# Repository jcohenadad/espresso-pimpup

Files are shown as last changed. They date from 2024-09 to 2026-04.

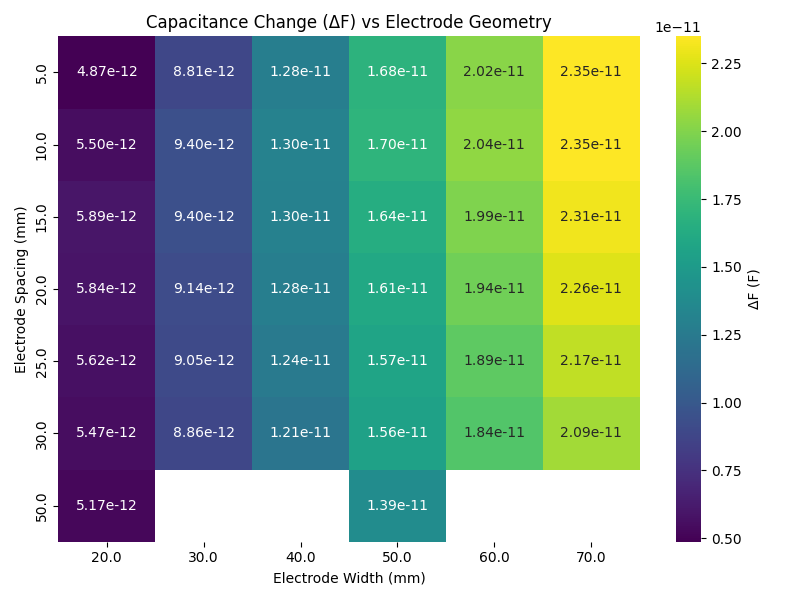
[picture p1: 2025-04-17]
CST/result_sweep.png

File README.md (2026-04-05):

# Espresso pimp up ☕

DIY project to pimp up my espresso machine to display various measures

## Material

- Power
  - [MEAN WELL USA Inc. RS-15-5 AC/DC CONVERTER 5V 15W](https://www.digikey.ca/en/products/detail/mean-well-usa-inc/RS-15-5/7706168)
- Display
  - [Graphic LCD Display Module IPS (In-Plane Switching) SPI 1.69"](https://www.digikey.com/en/products/detail/seeed-technology-co-ltd/104990802/21526011)
  - [CONN HEADER SMD 8POS 1.25MM](https://www.digikey.ca/en/products/detail/hirose-electric-co-ltd/DF13C-8P-1-25V-21/3977750)
  - [8 Position (pitch 1.25mm) Cable Assembly Rectangular Socket to Socket 450.00mm](https://www.digikey.ca/en/products/detail/molex/0151340805/6198210)
  - 4x 2mm metric threading screws https://github.com/jcohenadad/espresso-pimpup/issues/42
- Temperature
  - [K Type Thermocouple Temperature Sensor](https://www.amazon.ca/MECCANIXITY-Thermocouple-Temperature-Sensor-Stainless/dp/B0C998V2DP)
  - [Thermocouple Amplifier MAX31855](https://www.amazon.ca/dp/B00SK8NDAI)

### Water level
| Item | Quantity | Description |
| ---- | --- | --- |
| [FDC1004DGSR](https://www.digikey.ca/en/products/detail/texas-instruments/FDC1004DGSR/5250523) | 1 | 4-channel 16-bit capacitance-to-digital converter |
| [LCQT-MSOP10](https://www.digikey.ca/en/products/detail/aries-electronics/LCQT-MSOP10/4754589) | 1 | To create the breakout board for the FDC1004 chip |
| [WR-PHD 2.54 MM SOCKET HEADER 5 P](https://www.digikey.ca/en/products/detail/w%C3%BCrth-elektronik/61300511821/16608594) | 2 | To plug the breakout board on the main PCB |
| [C0603C104M4RACTU](https://www.digikey.ca/en/products/detail/kemet/C0603C104M4RACTU/411098) | 1 | Decoupling Capacitor |
| [RC0603FR-074K7L](https://www.digikey.ca/en/products/detail/yageo/rc0603fr-074k7l/727212) | 2 | Pull-up Resistors for I2C |

## Pictures

https://photos.app.goo.gl/eQaupZRUNoXkHYi69

## Upload/Monitor Arduino code

Using CLI (you need to adjust the correct port):

```shell
# Compile
arduino-cli compile --fqbn arduino:avr:nano ArduinoEspressoSensor/
# Upload
arduino-cli upload ArduinoEspressoSensor -b arduino:avr:nano -p /dev/cu.usbserial-BG0046HD
# Monitor
arduino-cli monitor -p /dev/cu.usbserial-BG0046HD --config 9600
```

## Calibration

Before using the setup, some calibration is needed.

### Water tank

- Activate debug mode: `DEBUG_CAPACITANCE false`
- Check capacitance values for empty and full tank.
- Enter respective values for variables `LOWER_BOUND` and `UPPER_BOUND`

### Timer

Timer for brewing duration is based on the variable `pressureThreshold`, which can be adjusted if needed.

## References

This project is inspired by the following sources:
- https://www.youtube.com/watch?v=4V0a9dfkx9Q
- https://github.com/PostModernDesign/RancilioBrain/blob/master/RancilioBrain.md
- https://github.com/urbantrout/bleeding-edge-ranciliopid/tree/master?tab=readme-ov-file
- https://clevercoffee.de/rancilio-silvia-demontage/
- https://clevercoffee.de/gaggia-classic-9480/
- https://clevercoffee.de/rancilio-silvia-e-konstantin/
- https://clevercoffee.de/rancilio-silvia-e-sebi/
- https://www.youtube.com/watch?v=AzQRCUg6E9g
- https://optimalprimate.github.io/projects/2020/11/14/coffee.html
- https://github.com/mwood77/koffie
  - https://www.seattlecoffeegear.com/cdn/shop/files/silvia-pid-installation-guide.pdf?v=8847236618586878957
- https://www.reddit.com/r/ranciliosilvia/search/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
- https://github.com/brycesub/silvia-pi?tab=readme-ov-file

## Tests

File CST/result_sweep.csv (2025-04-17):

3D Run ID | electrode_spacing | electrode_width | water_height | Mesh Pass | 1D Results\Es Solver\Capacitance Matrix\C potential, ground
1 | 10 | 20 | 20 | 6 | -2.1493e-12
2 | 10 | 50 | 20 | 6 | -3.38278e-12
3 | 50 | 20 | 20 | 6 | -6.30386e-13
4 | 50 | 50 | 20 | 6 | -1.57864e-12
5 | 10 | 20 | 180 | 6 | -7.64647e-12
6 | 10 | 50 | 180 | 5 | -2.03387e-11
7 | 50 | 20 | 180 | 6 | -5.80162e-12
8 | 50 | 50 | 180 | 6 | -1.5434e-11
9 | 5 | 20 | 20 | 6 | -3.60719e-12
10 | 5 | 30 | 20 | 6 | -4.11443e-12
11 | 5 | 40 | 20 | 6 | -4.1285e-12
12 | 5 | 50 | 20 | 6 | -4.49879e-12
13 | 5 | 60 | 20 | 6 | -5.18666e-12
14 | 5 | 70 | 20 | 6 | -5.56035e-12
15 | 10 | 30 | 20 | 6 | -2.61785e-12
16 | 10 | 40 | 20 | 6 | -2.92457e-12
17 | 10 | 60 | 20 | 6 | -3.7167e-12
18 | 10 | 70 | 20 | 6 | -4.18799e-12
19 | 15 | 20 | 20 | 6 | -1.49111e-12
20 | 15 | 30 | 20 | 6 | -1.97542e-12
21 | 15 | 40 | 20 | 6 | -2.36479e-12
22 | 15 | 50 | 20 | 6 | -2.82149e-12
23 | 15 | 60 | 20 | 5 | -3.23191e-12
24 | 15 | 70 | 20 | 6 | -3.53614e-12
25 | 20 | 20 | 20 | 6 | -1.18861e-12
26 | 20 | 30 | 20 | 6 | -1.60755e-12
27 | 20 | 40 | 20 | 6 | -2.05532e-12
28 | 20 | 50 | 20 | 6 | -2.48066e-12
29 | 20 | 60 | 20 | 6 | -2.84073e-12
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

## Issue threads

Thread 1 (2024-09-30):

Ultrasonic sensor does not work

jcohenadad, 2024-09-30:
I have the PWM DC5V Ultrasonic ranging sensor ultrasonic waterproof distance sensor waterproof probe RS485. It produces constant output between PWM and GND. It suggests it is likely relying on RS485 communication, which requires a RS485 to TTL converter module.

I might get another probe, such as the [DYP-A02YY Waterproof sensor](https://forum.arduino.cc/t/dyp-a02yy-waterproof-sensor/1154338). Links
- https://www.amazon.ca/-/fr/Taidacent-D%C3%A9tecteur-d%C3%A9tection-stationnement-ultrasonique/dp/B082D96911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
- UART: https://www.amazon.ca/dp/B0CLVSQ7H5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
- https://www.aliexpress.com/item/1005003107797097.html

Related resource:
- https://forum.arduino.cc/t/help-understanding-breaking-down-this-code/699362/12
- https://forum.arduino.cc/t/monitoring-the-level-of-an-underground-water-tank/1147820/29

Datasheet of sensor: https://www.dypcn.com/uploads/A02-Datasheet.pdf
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

jcohenadad, 2024-10-15:
Additional debugging, useful ressource:
- https://forum.arduino.cc/t/dyp-a02yy-waterproof-sensor/1154338/18
- https://forum.arduino.cc/t/sensor-shows-the-same-value-a02yyuw/859239/7

jcohenadad, 2024-10-17:
Ended up buying an [HC-SR04](https://www.amazon.ca/dp/B07RGB4W8V?ref=ppx_yo2ov_dt_b_fed_asin_title).

Closed 2024-12-06.

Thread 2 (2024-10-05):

Timer for brew switch button

jcohenadad, 2024-10-05:
To implement a timer for measuring the duration of an espresso shot on the Rancilio Silvia machine, you'll need to wire the Arduino to detect when the brew button is switched on and off. Here's a guide on how to connect the Arduino to the machine and the code to control the timer:

1. Wiring the Arduino to the Rancilio Silvia Machine:
The Rancilio Silvia’s brew switch controls the power to the pump or a solenoid valve. We can use the state of this switch to detect when the brew starts and stops. One way to do this is by using an opto-isolator (optocoupler) or a relay module to safely interface the 120V AC or 230V AC voltage with the Arduino, which operates at a lower voltage.

Note: If you're not comfortable working with high voltage, consider using a safe sensor like a current sensor or work with an electronics professional.

Components Needed:
Optocoupler (Opto-isolator): For isolating the high voltage AC and low voltage DC.
Relay Module: As an alternative to the optocoupler, a relay module can be used to interface high voltage safely.
Resistors (for current limiting if needed).
Wires.
Arduino Board.
Basic Wiring Steps:
Identify the Brew Switch on the Rancilio Silvia:

Open the case of the Rancilio Silvia to access the brew switch.
Find the two terminals of the brew switch where it connects to the pump or solenoid valve.
Connect the Optocoupler or Relay to the Brew Switch:

Connect the input side of the optocoupler or relay module to the brew switch terminals.
When the switch is turned on, it should close the circuit on the input side, allowing the optocoupler or relay to activate.
Connect the Optocoupler or Relay to the Arduino:

The output side of the optocoupler or relay should connect to a digital input pin on the Arduino (e.g., Digital Pin 2).
Connect the GND of the Arduino to the GND of the optocoupler/relay module.
Optionally, connect a pull-down resistor (e.g., 10kΩ) between the digital input pin and GND to ensure the pin reads LOW when the brew switch is off.

Here's a simple code example that starts a timer when the brew switch is turned on and stops it when the switch is turned off:

```c
// Define the pin connected to the optocoupler/relay output
#define BREW_SWITCH_PIN 2   // Digital pin 2 for brew switch input

// Variables to store timing information
unsigned long startTime = 0;     // Store start time
unsigned long shotDuration = 0;  // Store shot duration

// Variable to keep track of brew switch state
bool isBrewing = false;

void setup() {
  // Initialize the serial communication
  Serial.begin(9600);

  // Set the brew switch pin as input
  pinMode(BREW_SWITCH_PIN, INPUT);

  // Ensure pin starts LOW (brew switch off)
  digitalWrite(BREW_SWITCH_PIN, LOW);

  // Print initial message
  Serial.println("Waiting for brew to start...");
}

void loop() {
  // Read the state of the brew switch
  bool brewSwitchState = digitalRead(BREW_SWITCH_PIN);

  // Check if brew switch has been turned on (HIGH)
  if (brewSwitchState == HIGH && !isBrewing) {
    // Brew just started
    startTime = millis();   // Record the start time
    isBrewing = true;       // Set brewing state to true
    Serial.println("Brew started!");

  } else if (brewSwitchState == LOW && isBrewing) {
    // Brew just stopped
    shotDuration = millis() - startTime;  // Calculate shot duration
    isBrewing = false;                    // Reset brewing state

    // Print the duration in seconds
    Serial.print("Brew stopped! Duration: ");
    Serial.print(shotDuration / 1000.0);  // Convert to seconds
    Serial.println(" seconds");

    // Reset start time for the next shot
    startTime = 0;
  }

  // Add a small delay to debounce the switch
  delay(50);
}
```

Source: ChatGPT. Prompt:
~~~
I'd like to count the duration of a shot of espresso using arduino. When the user switches on the brew button on the rancilio silvia machine, the timer starts, and when switch is off, the timer stops. What would be the wiring connection, and arduino code for this?
~~~

jcohenadad, 2024-10-05:
Alternative option: Using current sensor

Sure! Here's the first option written in Markdown format.

---

# Using a Non-Invasive Current Sensor to Detect Brew Switch State

This solution uses a **non-invasive current sensor** to detect when the brew switch on your **Rancilio Silvia espresso machine** is turned on or off. This method is safe, simple, and does not require making direct electrical connections to the high-voltage AC circuit.

## 1. Components Needed

1. **SCT-013-000 Non-Invasive AC Current Sensor**
   - Detects AC current through magnetic induction.
   - Available in different current ratings (e.g., 5A, 10A, 30A).

2. **Burden Resistor (if not built-in)**: 33Ω to 68Ω resistor (needed if the current sensor does not include a built-in burden resistor).

3. **Arduino Board**: Any Arduino (e.g., Uno, Nano) to read the current sensor output.

4. **Jumper Wires**: For connections between the sensor and the Arduino.

## 2. Wiring Instructions

1. **Connect the Current Sensor to the AC Wire:**
   - Clip the **current sensor** around the AC wire connected to the **brew switch** or the pump.
   - The sensor should be clamped around only **one wire** (either live or neutral, not both).

2. **Wiring the Sensor to the Arduino:**
   - Connect the **sensor’s output signal wire** to an **analog input pin** on the Arduino (e.g., `A0`).
   - If your sensor has three wires (`VCC`, `GND`, and `Signal`):
     - **VCC** → **5V** on the Arduino.
     - **GND** → **GND** on the Arduino.
     - **Signal** → **Analog Pin A0** on the Arduino.

3. **Verify Sensor Orientation:**
   - Ensure the current sensor is positioned correctly with the arrow indicating the current flow direction.
   - If using a sensor without a built-in burden resistor, connect the burden resistor across the sensor’s output terminals.

## 3. Arduino Code for Current Sensor

The following code reads the analog signal from the current sensor and determines whether the brew switch is on or off based on a predefined current threshold.

```cpp
#define CURRENT_SENSOR_PIN A0  // Analog pin to read current sensor value
const int threshold = 50;      // Adjust this threshold based on the sensor's output

bool isBrewing = false;
unsigned long startTime = 0;
unsigned long shotDuration = 0;

void setup() {
  Serial.begin(9600);  // Initialize serial communication
}

void loop() {
  // Read the analog value from the current sensor
  int sensorValue = analogRead(CURRENT_SENSOR_PIN);

  // If current is detected (above threshold), it means the brew switch is on
  if (sensorValue > threshold && !isBrewing) {
    startTime = millis();  // Start timing
    isBrewing = true;
    Serial.println("Brew started!");
  }
  // If current drops below threshold, it means the brew switch is off
  else if (sensorValue <= threshold && isBrewing) {
    shotDuration = millis() - startTime;  // Calculate shot duration
    isBrewing = false;
    Serial.print("Brew stopped! Duration: ");
    Serial.print(shotDuration / 1000.0);  // Convert duration to seconds
    Serial.println(" seconds");
  }

  delay(100);  // Small delay to avoid rapid readings
}
```

### Explanation:
1. **Reading Sensor Values:**
   - The code reads the analog value from the current sensor connected to `CURRENT_SENSOR_PIN` (e.g., `A0`).

2. **Setting a Current Threshold:**
   - The `threshold` value is used to determine if current is flowing through the wire (indicating the brew switch is on).
   - Adjust this threshold value based on the specific output of your sensor.

3. **Starting and Stopping the Timer:**
   - When the current value is above the threshold, it indicates that the brew switch is on, and the timer starts.
   - When the current value drops below the threshold, it indicates that the brew switch is off, and the timer stops.

## 4. Testing and Calibration

1. **Upload the Code to the Arduino:**
   - Use the Arduino IDE to upload the code to your Arduino board.

2. **Open the Serial Monitor:**
   - Set the baud rate to `9600` in the Serial Monitor.
   - Observe the start and stop messages along with the shot duration as you toggle the brew switch on and off.

3. **Adjust the Threshold Value:**
   - If the sensor does not reliably detect the brew switch state, adjust the `threshold` value in the code.
   - Increase or decrease the threshold until the sensor correctly detects when the switch is turned on and off.

## 5. Advantages of Using a Non-Invasive Current Sensor

- **Safety**: No direct electrical connection to high-voltage circuits.
- **Easy Installation**: Can be easily clamped onto an existing wire.
- **Cost-Effective**: Typically cheaper than using bi-directional SSRs or complex detection methods.

## 6. Considerations for Accurate Readings

- Ensure that the current sensor is only clamped around one wire (live or neutral). Clamping around both wires will result in zero reading due to phase cancellation.
- If the sensor’s output fluctuates too much, consider adding a moving average filter or noise suppression algorithm to the code.

---

Let me know if you'd like to see additional options or have any specific questions about implementing this solution!

jcohenadad, 2024-10-05:
# Best solution

Given that I need something to power the arduino, it makes sense to use the AC power line anyway. So one option would be to
- use the power line and convert it using an AC/DC converter to power the arduino
- use an Optocoupler to detect the brew switch

description below:

Given that you'd like to **power the Arduino using the espresso machine’s power supply** and detect the activation of the brew switch, we need to focus on a solution that provides:

1. **Safe power conversion** to step down the AC voltage to a suitable DC voltage for the Arduino.
2. **Reliable detection** of the brew switch activation while ensuring isolation and safety.

Here’s how you can achieve both goals:

## 1. **Powering the Arduino from the Espresso Machine**

The Rancilio Silvia operates on a high AC voltage (120V AC or 230V AC depending on your region). To power the Arduino, you need to step down the AC voltage to a safe DC voltage (e.g., 5V or 9V DC).
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
jcohenadad, 2024-10-05:
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

jcohenadad, 2024-10-05:
Little room for optocoupler behind switch... maybe a current probe is better.

jcohenadad, 2024-10-05:
Alternatively, I use no additional sensor associated with the switch, and I just rely on the pressure from the pump!!!

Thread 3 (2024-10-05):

Circuits/pictures of Rancilio Silvia

jcohenadad, 2024-10-05:
https://github.com/PostModernDesign/RancilioBrain/blob/master/RancilioBrain.md
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

jcohenadad, 2024-10-05:
https://www.home-barista.com/repairs/rancilio-s20-wiring-scheme-t48032.html
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

jcohenadad, 2024-10-05:
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

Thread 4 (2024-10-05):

Measuring pressure

jcohenadad, 2024-10-05:

jcohenadad, 2024-10-13:
Connection:

https://europe1.discourse-cdn.com/arduino/original/4X/5/9/3/59366f289c73117e1dce3a2158b3be3db8866f70.jpeg

jcohenadad, 2024-10-13:
I'm getting a lot of fluctuations:

<details><summary>Terminal output</summary>

```console
~~~
elsius temperature: 23.75
2.50 bar pressure with: 0.62V measured voltage.
Celsius temperature: 23.75
-0.92 bar pressure with: 0.45V measured voltage.
Celsius temperature: 23.75
-0.82 bar pressure with: 0.46V measured voltage.
Celsius temperature: 23.75
1.04 bar pressure with: 0.55V measured voltage.
Celsius temperature: 23.81
0.16 bar pressure with: 0.51V measured voltage.
Celsius temperature: 23.87
-2.38 bar pressure with: 0.38V measured voltage.
Celsius temperature: 23.81
-0.04 bar pressure with: 0.50V measured voltage.
Celsius temperature: 23.87
0.35 bar pressure with: 0.52V measured voltage.
Celsius temperature: 23.81
0.84 bar pressure with: 0.54V measured voltage.
Celsius temperature: 23.81
0.64 bar pressure with: 0.53V measured voltage.
Celsius temperature: 23.81
0.94 bar pressure with: 0.55V measured voltage.
Celsius temperature: 23.81
-0.62 bar pressure with: 0.47V measured voltage.
Celsius temperature: 23.81
-0.53 bar pressure with: 0.47V measured voltage.
Celsius temperature: 23.75
1.91 bar pressure with: 0.60V measured voltage.
Celsius temperature: 23.69
-0.53 bar pressure with: 0.47V measured voltage.
Celsius temperature: 23.69
2.99 bar pressure with: 0.65V measured voltage.
Celsius temperature: 23.69
-0.14 bar pressure with: 0.49V measured voltage.
Celsius temperature: 23.81
-1.21 bar pressure with: 0.44V measured voltage.
Celsius temperature: 23.81
-1.02 bar pressure with: 0.45V measured voltage.
Celsius temperature: 23.81
1.72 bar pressure with: 0.59V measured voltage.
```

</details>

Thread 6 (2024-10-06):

Powering the Arduino

jcohenadad, 2024-10-06:

jcohenadad, 2024-10-07:
Connection (from https://clevercoffee.de/rancilio-silvia-e-sebi/)

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

jcohenadad, 2024-10-07:
Forking the connection from the main power switch, I need those connectors:

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

https://www.youtube.com/watch?v=AzQRCUg6E9g&ab_channel=BeatTheBushDIY

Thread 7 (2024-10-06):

Interfacing the pressure sensor with Arduino

jcohenadad, 2024-10-06:
The pressure sensor has ferrules terminal. I need to find a way to interface them with the grove board of the arduino.

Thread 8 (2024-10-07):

Connectivity with Arduino board

jcohenadad, 2024-10-07:
Terminal screw is definitely more convenient/versatile than grove board adapter. See eg: https://github.com/jcohenadad/espresso-pimpup/issues/6#issuecomment-2395761560

Alternatively, I could use an Arduino Nano with an [expansion board](https://www.digikey.ca/en/products/detail/ptsolns/PTS-00026-211/17878784?productid=17878784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)

jcohenadad, 2024-11-13:
Examples of Arduino and connectivity:

From: https://clevercoffee.de/rancilio-silvia-e-sebi/

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

jcohenadad, 2025-04-25:
PIN Layout for nano ([source](https://www.mouser.com/pdfdocs/Gravitech_Arduino_Nano3_0.pdf)):

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

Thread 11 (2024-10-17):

How to connect HC-SR04 sensor

jcohenadad, 2024-10-17:
Pins

jcohenadad, 2024-12-05:
One option is to insert the 303C-C3018-25-05_C_1 inside the water tank, and put the 303C-541219-25-05_C_1 on the lid:

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

Pros:
- elegant and robust
Cons:
- requires to 'butcher' the water tank

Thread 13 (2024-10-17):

Consider Arduino Nano with screw terminal extension

jcohenadad, 2024-10-17:
More robust and versatile than grove connection. Few examples:
- [Amazon](https://www.amazon.ca/KeeYees-Expansion-Terminal-Adapter-ATMEGA328P-AU/dp/B07YTZSR72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). Cons: no additional power input
- [Digikey](https://www.digikey.ca/en/products/detail/ptsolns/PTS-00021-211/17878783?productid=17878783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) Cons: have to mount, pros: additional DC/GND pins
- [TME](https://www.tme.com/ca/en/details/asx00037/arduino-solutions/arduino/arduino-nano-screw-terminal-adapter/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[PLA]%20EN&gad_source=1&gclid=CjwKCAjw68K4BhAuEiwAylp3kqlZIe5WwfeYprrSZA1nM84-rrNFoJoykjXdBJsvr8xe3TWWWH76rhoCD-EQAvD_BwE) Pros: room for additional connectics. Seems like an excellent choice!

jcohenadad, 2024-11-25:
Another thing to consider: I would need access to GND and Vcc for each sensor + OLED, that's 4x. Possible solutions:
- Split terminals
  - cons: sensors cable have GND, Vcc and additional cables clusters-- it will be a mess to separate them to reach the splitter.
- Stripboard or custom PCB (eg [here](https://forum.arduino.cc/t/required-multiple-ground-point-and-vcc-points-in-nano/577964))
  - cons: takes more time

jcohenadad, 2025-06-20:
no-- current design is good. See notably #26

Closed 2025-06-20.

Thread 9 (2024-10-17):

USB port behavior connecting to Arduino

jcohenadad, 2024-10-17:
When connecting the Arduino to my Macbook, the Arduino is powered and code can be downloaded to the Arduino, however the 5VDC supply to the various sensors connected to the Arduino is unreliable.

Related references:
- https://discussions.apple.com/thread/255536060?sortBy=rank
- https://forum.arduino.cc/t/problem-with-using-arduino-with-mac-which-has-only-usb-c-ports/675193

jcohenadad, 2024-10-17:
Issue was cabling...

Closed 2024-10-17.

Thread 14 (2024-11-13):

Temperature probe

jcohenadad, 2024-11-13:
Desired specs
- Fast reading time to avoid https://github.com/jcohenadad/espresso-pimpup/issues/18
  - Eg: RTD with a MAX31865
- Stable installation on the boiler

From: https://optimalprimate.github.io/projects/2020/11/14/coffee.html

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

jcohenadad, 2024-11-13:
Another possibility to attached the probe is to put it on the side of the cylinder, and attach it with a metal wraping system, with a thermal paste:

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

jcohenadad, 2024-11-24:
That seems ideal: to be screwed on the boiler directly, using one of the screw that is attached to the thermostat:

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

Source: https://www.te.com/en/product-CAT-RTD0036.html

jcohenadad, 2024-11-24:
Alternatively, if I don't find an appropriate washer-style RTD, maybe I can buy a cylindrical probe, and interface it with a Closed Ring Tongue Terminal:

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

jcohenadad, 2025-04-10:
ok, I ended up buying the following:
- https://www.amazon.ca/MECCANIXITY-Thermocouple-Temperature-Sensor-Stainless/dp/B0C998V2DP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
- thermocouple amplifier max31855

Closed 2025-06-20.

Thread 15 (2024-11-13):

Location and attachment of PCB

jcohenadad, 2024-11-13:
On the side, using sticking plastic thingy:

From: https://clevercoffee.de/gaggia-classic-9480/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

jcohenadad, 2025-04-28:
# At the bottom, close to the pump

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

jcohenadad, 2025-05-02:
For attachment, use sheet metal screws or self-tapping screws.

jcohenadad, 2025-06-20:
good location-- we can close

Closed 2025-06-20.

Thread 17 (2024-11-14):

Update OLED display for bigger and enclosed solution

jcohenadad, 2024-11-14:
Related to #16

❌ https://www.digikey.com/en/products/detail/arduino/ASX00039/21443321
10x8cm, way too big!
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

jcohenadad, 2024-11-14:
✅  https://www.digikey.com/en/products/detail/seeed-technology-co-ltd/104990802/21526011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
31x39 mm

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

Closed 2024-12-19.

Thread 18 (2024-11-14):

Slow loop

jcohenadad, 2024-11-14:
Trying to figure out where the bottleneck comes from...

- OLED display: Nope

jcohenadad, 2024-11-14:
Trying reducing resolution:
~~~
  sensors.setResolution(9);
~~~

jcohenadad, 2024-11-14:
I tried asynchronous communication with the temp probe, but it results in weird freeze time every 0.5s or so

<details><summary>Terminal output</summary>

```console
#include <OneWire.h>
#include <DallasTemperature.h>

// Data wire is connected to pin 2
#define ONE_WIRE_BUS 2

// Setup a oneWire instance
OneWire oneWire(ONE_WIRE_BUS);

// Pass oneWire reference to DallasTemperature
DallasTemperature sensors(&oneWire);

// Timing variables
unsigned long previousMillis = 0;
const unsigned long conversionInterval = 750;  // Time needed for conversion at 12-bit resolution
bool temperatureRequested = false;
float currentTemperature = 0.0;

void setup() {
  Serial.begin(9600);
  sensors.begin();
}

void loop() {
  unsigned long currentMillis = millis();

  // Step 1: Request temperature conversion if not already requested
  if (!temperatureRequested) {
    sensors.requestTemperatures();  // Start conversion
    temperatureRequested = true;
    previousMillis = currentMillis;  // Record the time when the conversion started
    Serial.println("Temperature conversion requested...");
  }

  // Step 2: Check if enough time has passed for conversion to complete
  if (temperatureRequested && (currentMillis - previousMillis >= conversionInterval)) {
    // Read the temperature
    currentTemperature = sensors.getTempCByIndex(0);
    temperatureRequested = false;  // Reset the flag
    Serial.print("Temperature: ");
    Serial.print(currentTemperature, 2);
    Serial.println(" °C");
  }

  // Step 3: Perform other non-blocking tasks
  handleOtherTasks();
}

void handleOtherTasks() {
  // Example: Blink an LED or handle other sensors
  static unsigned long lastBlink = 0;
  const unsigned long blinkInterval = 200;  // Blink every 200 ms
  unsigned long now = millis();

  if (now - lastBlink >= blinkInterval) {
    lastBlink = now;
    digitalWrite(LED_BUILTIN, !digitalRead(LED_BUILTIN));  // Toggle LED
  }

  // You can add additional non-blocking tasks here
}
```

</details>

So not a viable solution.

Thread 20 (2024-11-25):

Designing PCB

jcohenadad, 2024-11-25:
nano footprint:
- https://forum.arduino.cc/t/arduino-mini-kicad-lib-and-mod-files/125146
- https://forum.kicad.info/t/arduino-nano-pcb-files/8307/2

Amazing list of 3D designs for connectors and other PCB-related things: http://smisioto.no-ip.org/elettronica/kicad/kicad-en.htm

Closed 2025-06-20.

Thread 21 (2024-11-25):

Wiring and programming the ST7789V2 LCD screen

jcohenadad, 2024-11-25:
Some resource:
- https://gist.github.com/MazeW/80cbdd4476d27a4e29491c8038855849
- https://forum.arduino.cc/t/st7789-2-8inch-display-with-arduino-nano/1239476
- https://simple-circuit.com/arduino-st7789-ips-tft-display-example/

jcohenadad, 2024-12-19:
I ended up buying https://github.com/jcohenadad/espresso-pimpup/issues/17#issuecomment-2477268453

Closed 2024-12-19.

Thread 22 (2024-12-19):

Wiring and programming of new LCD 1"69' display

jcohenadad, 2024-12-19:
✅  https://www.digikey.com/en/products/detail/seeed-technology-co-ltd/104990802/21526011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
31x39 mm

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

Relevant links:
- https://www.seeedstudio.com/1-69inch-240-280-Resolution-IPS-LCD-Display-Module-p-5755.html
- https://wiki.seeedstudio.com/1-69inch_lcd_spi_display/
- https://www.waveshare.com/w/upload/2/2b/1.69inch_LCD_Module.pdf
- dimension: https://www.waveshare.com/w/upload/4/41/1.69inch_LCD_Module_2Ddrawing.pdf
- https://www.waveshare.com/w/upload/c/c9/ST7789V2.pdf

_Originally posted by @jcohenadad in https://github.com/jcohenadad/espresso-pimpup/issues/17#issuecomment-2477268453_

jcohenadad, 2024-12-19:
i'm doing what's described in https://www.waveshare.com/wiki/1.69inch_LCD_Module#Hardware_Connection_3, but i get

```console
/Users/julien/Desktop/LCD_Module_code/Arduino/LCD_1inch69/font12.cpp:110:1: error: initializer-string for array of chars is too long [-fpermissive]
 };
 ^
/Users/julien/Desktop/LCD_Module_code/Arduino/LCD_1inch69/font12.cpp:110:1: error: initializer-string for array of chars is too long [-fpermissive]
/Users/julien/Desktop/LCD_Module_code/Arduino/LCD_1inch69/font12.cpp:110:1: error: initializer-string for array of chars is too long [-fpermissive]
/Users/julien/Desktop/LCD_Module_code/Arduino/LCD_1inch69/font12.cpp:110:1: error: initializer-string for array of chars is too long [-fpermissive]
/Users/julien/Desktop/LCD_Module_code/Arduino/LCD_1inch69/font12.cpp:110:1: error: initializer-string for array of chars is too long [-fpermissive]
/Users/julien/Desktop/LCD_Module_code/Arduino/LCD_1inch69/font24CN.cpp:455:1: error: initializer-string for array of chars is too long [-fpermissive]
 };
 ^
/Users/julien/Desktop/LCD_Module_code/Arduino/LCD_1inch69/font24CN.cpp:455:1: error: initializer-string for array of chars is too long [-fpermissive]
/Users/julien/Desktop/LCD_Module_code/Arduino/LCD_1inch69/font24CN.cpp:455:1: error: initializer-string for array of chars is too long [-fpermissive]
/Users/julien/Desktop/LCD_Module_code/Arduino/LCD_1inch69/font24CN.cpp:455:1: error: initializer-string for array of chars is too long [-fpermissive]
/Users/julien/Desktop/LCD_Module_code/Arduino/LCD_1inch69/font24CN.cpp:455:1: error: initializer-string for array of chars is too long [-fpermissive]
/Users/julien/Desktop/LCD_Module_code/Arduino/LCD_1inch69/font24CN.cpp:455:1: error: initializer-string for array of chars is too long [-fpermissive]
/Users/julien/Desktop/LCD_Module_code/Arduino/LCD_1inch69/font24CN.cpp:455:1: error: initializer-string for array of chars is too long [-fpermissive]
/Users/julien/Desktop/LCD_Module_code/Arduino/LCD_1inch69/font24CN.cpp:455:1: error: initializer-string for array of chars is too long [-fpermissive]
/Users/julien/Desktop/LCD_Module_code/Arduino/LCD_1inch69/font24CN.cpp:455:1: error: initializer-string for array of chars is too long [-fpermissive]
/Users/julien/Desktop/LCD_Module_code/Arduino/LCD_1inch69/font24CN.cpp:455:1: error: initializer-string for array of chars is too long [-fpermissive]
/Users/julien/Desktop/LCD_Module_code/Arduino/LCD_1inch69/font24CN.cpp:455:1: error: initializer-string for array of chars is too long [-fpermissive]
/Users/julien/Desktop/LCD_Module_code/Arduino/LCD_1inch69/font24CN.cpp:455:1: error: initializer-string for array of chars is too long [-fpermissive]
/Users/julien/Desktop/LCD_Module_code/Arduino/LCD_1inch69/font24CN.cpp:455:1: error: initializer-string for array of chars is too long [-fpermissive]
/Users/julien/Desktop/LCD_Module_code/Arduino/LCD_1inch69/font24CN.cpp:455:1: error: initializer-string for array of chars is too long [-fpermissive]
/Users/julien/Desktop/LCD_Module_code/Arduino/LCD_1inch69/font24CN.cpp:455:1: error: initializer-string for array of chars is too long [-fpermissive]
/Users/julien/Desktop/LCD_Module_code/Arduino/LCD_1inch69/font24CN.cpp:455:1: error: initializer-string for array of chars is too long [-fpermissive]
/Users/julien/Desktop/LCD_Module_code/Arduino/LCD_1inch69/font24CN.cpp:455:1: error: initializer-string for array of chars is too long [-fpermissive]
/Users/julien/Desktop/LCD_Module_code/Arduino/LCD_1inch69/font24CN.cpp:455:1: error: initializer-string for array of chars is too long [-fpermissive]
/Users/julien/Desktop/LCD_Module_code/Arduino/LCD_1inch69/font24CN.cpp:455:1: error: initializer-string for array of chars is too long [-fpermissive]
/Users/julien/Desktop/LCD_Module_code/Arduino/LCD_1inch69/font24CN.cpp:455:1: error: initializer-string for array of chars is too long [-fpermissive]
/Users/julien/Desktop/LCD_Module_code/Arduino/LCD_1inch69/font24CN.cpp:455:1: error: initializer-string for array of chars is too long [-fpermissive]
/Users/julien/Desktop/LCD_Module_code/Arduino/LCD_1inch69/font24CN.cpp:455:1: error: initializer-string for array of chars is too long [-fpermissive]
/Users/julien/Desktop/LCD_Module_code/Arduino/LCD_1inch69/font24CN.cpp:455:1: error: initializer-string for array of chars is too long [-fpermissive]
/Users/julien/Desktop/LCD_Module_code/Arduino/LCD_1inch69/GUI_Paint.cpp: In function 'void Paint_DrawString_CN(uint16_t, uint16_t, const char*, cFONT*, uint16_t, uint16_t)':
/Users/julien/Desktop/LCD_Module_code/Arduino/LCD_1inch69/GUI_Paint.cpp:499:32: error: invalid conversion from 'const char*' to 'const unsigned char*' [-fpermissive]
  const unsigned char* p_text = pString;
                                ^~~~~~~
/Users/julien/Desktop/LCD_Module_code/Arduino/LCD_1inch69/DEV_Config.cpp: In function 'void Config_Init()':
/Users/julien/Desktop/LCD_Module_code/Arduino/LCD_1inch69/DEV_Config.cpp:49:9: error: 'class arduino::ArduinoSPI' has no member named 'setDataMode'
     SPI.setDataMode(SPI_MODE3);
         ^~~~~~~~~~~
/Users/julien/Desktop/LCD_Module_code/Arduino/LCD_1inch69/DEV_Config.cpp:50:9: error: 'class arduino::ArduinoSPI' has no member named 'setBitOrder'
     SPI.setBitOrder(MSBFIRST);
         ^~~~~~~~~~~
/Users/julien/Desktop/LCD_Module_code/Arduino/LCD_1inch69/DEV_Config.cpp:51:9: error: 'class arduino::ArduinoSPI' has no member named 'setClockDivider'
     SPI.setClockDivider(SPI_CLOCK_DIV2);
         ^~~~~~~~~~~~~~~
/Users/julien/Desktop/LCD_Module_code/Arduino/LCD_1inch69/DEV_Config.cpp:51:25: error: 'SPI_CLOCK_DIV2' was not declared in this scope
     SPI.setClockDivider(SPI_CLOCK_DIV2);
                         ^~~~~~~~~~~~~~
/Users/julien/Desktop/LCD_Module_code/Arduino/LCD_1inch69/DEV_Config.cpp:51:25: note: suggested alternative: 'CGC_CLOCK_PLL2'
     SPI.setClockDivider(SPI_CLOCK_DIV2);
                         ^~~~~~~~~~~~~~
                         CGC_CLOCK_PLL2

exit status 1

Compilation error: initializer-string for array of chars is too long [-fpermissive]
```

Looks like the code might not be compatible with the updated libraries.

jcohenadad, 2024-12-19:
Trying example from library: https://github.com/adafruit/Adafruit-ST7735-Library/tree/master

getting this: https://github.com/adafruit/Adafruit-ST7735-Library/issues/100

jcohenadad, 2024-12-19:
Unclear if I should use 3.3V or 5V. This says both can be used (https://www.adafruit.com/product/5206):
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

but this says 3.3V only (https://simple-circuit.com/arduino-st7789-ips-tft-display-example/):
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

jcohenadad, 2024-12-19:
OK I figured! The connectivity listed in https://www.waveshare.com/wiki/1.69inch_LCD_Module#Hardware_Connection_3 is wrong. D7 and D8 need to be inverted. The correct wiring is the following:

| **LCD** | **UNO** |
|---------|---------|
| VCC     | 5V      |
| GND     | GND     |
| DIN     | D11     |
| CLK     | D13     |
| CS      | D10     |
| DC      | D8      |
| RST     | D7      |
| BL      | D9      |

jcohenadad, 2024-12-19:
Displaying in the `setup()` works, but not in the `loop()`. However, if i put "  tft.init(240, 280); " inside the loop() function, it works. How come? Is it really necessary to reinitialize?

Apparently not. Maybe an issue with the wiring. According to chatGPT: If the RST pin is floating or not properly set, the display may not initialize correctly. tft.init(...) inside the loop() essentially resets the display each time.

I redefined 9 as 7, but it didn't help.

jcohenadad, 2024-12-19:
ok, after doing some experiments:  BL needs to be connected to either D7 or 5V (the 5V is easier, it frees D7).

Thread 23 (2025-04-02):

Water level using capacitive displacement sensor

jcohenadad, 2025-04-02:
Alternatively to the ultrasound-based sensor, it would be more elegant to use capacitive displacement sensor:
- https://forum.arduino.cc/t/water-level-sensor-with-capacitance-sensing/1321210
- https://forum.arduino.cc/t/how-does-this-sensor-measure-liquid-level/171405/5

Also relevant links describing solution with the probe _inside_ the liquide:
- https://playwithcircuit.com/water-level-sensor-arduino-tutorial/
- https://projecthub.arduino.cc/Pedro52/arduino-esp32-diy-water-level-sensor-and-diy-level-indicator-a8d507

jcohenadad, 2025-04-02:
Additional thing to consider: Temperature Compensation: Capacitance can drift with temperature, but if only using this for basic level detection (not precision measurement), it's usually not a problem.

I can also add a “reference” sensor away from the water to compensate for ambient changes.

jcohenadad, 2025-04-02:
Exemple of prototype:

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

Here’s the full Arduino code that matches the schematic for a capacitive water level sensor using external electrodes, based on the RC timing method:

```
// Capacitive Water Level Sensor (RC method)
// Electrode A = charge pin (D2)
// Electrode B = sense pin (A0)
// Optional: 10kΩ resistor between A0 and GND for faster discharge

const int chargePin = 2;  // Digital pin to charge electrode A
const int sensePin = A0;  // Analog pin to measure voltage from electrode B

long readCapacitance() {
  // Step 1: Discharge the capacitor (Electrode B)
  pinMode(sensePin, OUTPUT);
  digitalWrite(sensePin, LOW);
  delay(5); // Allow time to fully discharge

  // Step 2: Set sense pin to input to measure voltage
  pinMode(sensePin, INPUT);

  // Step 3: Charge through resistor from chargePin
  digitalWrite(chargePin, HIGH);

  long startTime = micros();

  // Step 4: Wait until the capacitor voltage crosses threshold
  while (analogRead(sensePin) < 600) {
    if ((micros() - startTime) > 3000) break; // timeout to avoid lock-up
  }

  long duration = micros() - startTime;

  // Step 5: Reset charge pin
  digitalWrite(chargePin, LOW);

  return duration;
}

void setup() {
  Serial.begin(9600);
  pinMode(chargePin, OUTPUT);
  digitalWrite(chargePin, LOW);  // Ensure charge pin starts low
}

void loop() {
  long capValue = readCapacitance();
  Serial.print("Capacitive reading: ");
  Serial.println(capValue);
  delay(500);
}
```

jcohenadad, 2025-04-02:
From the [FDC1004 capacitive sensor datasheet](https://www.ti.com/product/FDC1004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):

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

jcohenadad, 2025-04-12:
I don't find a breakout board for the FDC1004, so let's look into the FDC2214

jcohenadad, 2025-04-28:
Wiring of breakout board: https://github.com/Protocentral/ProtoCentral_fdc1004_breakout/blob/master/hardware/pc_fdc1004_brk_v3.pdf

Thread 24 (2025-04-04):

EM simulation to optimize electrode placement

jcohenadad, 2025-04-04:
EM simulation with 3D solver, such as CST, would provide optimal solution for electrode placement. This issue will describe simulation experiments.

jcohenadad, 2025-04-16:
# Meshing

Done at accuracy 10^-4

## Hexahedral

## Tetrahedral

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

jcohenadad, 2025-04-17:
Here is the result of the sweep, showing the maximum deltaF as a function of electrode width and spacing:

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

> [!IMPORTANT]
> Conclusion: I should design electrodes with maximum width and minimum spacing.

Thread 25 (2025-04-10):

Powering the MAX31855 Amp with the arduino

jcohenadad, 2025-04-10:
⚠️ MAX31855 is 3.3V-only — don’t connect it to 5V! It could damage the chip.

If your Nano runs at 5V logic, consider using:

A logic level shifter (simple BSS138 or voltage divider on MISO line)

Or power the MAX31855 and Arduino with 3.3V (less common)

jcohenadad, 2025-04-10:
After subsequent research, it seems like i can use the nano 3.3V output to power that amp

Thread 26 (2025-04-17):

Female header or directly solder the Arduino on the main PCB

jcohenadad, 2025-04-17:
Some thoughts: https://forum.kicad.info/t/arduino-scematic-symbol-and-footprint/23605/15

jcohenadad, 2025-06-20:
Went with female header

Closed 2025-06-20.

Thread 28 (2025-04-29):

Connecting graphic display

jcohenadad, 2025-04-29:
The 1.69 LCD display is compatible with an 8-pin GH1.25 cable.

I need longer cable, and male output. Ideally, it would also be a strip of attached cables for more convenient plugging on the screw terminal.

jcohenadad, 2025-06-20:
Let's go with a JST GH 1.25 footprint on the PCB

jcohenadad, 2025-06-20:
Fixed in [f4f06fa](https://github.com/jcohenadad/espresso-pimpup/commit/f4f06fad51292ab8f48c63e4d8ca89a4693bd101)

Closed 2025-06-20.

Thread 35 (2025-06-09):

Pressure probe too long

jcohenadad, 2025-06-09:
I ordered that one:

XDB401 Pro Coffee Machine Use SS316L Pressure Transducers
Pressure range: 12 BAR
Input voltage: 5V DC
Output signal: 0.5-4.5V
Thread: G1/8
Connector: Hirschmann DIN43650C | $3.00
Cable length: 0.5m
Accuracy: ±1%FS
Housing shell: 316L Stainless Steel
Measuring medium: water

The pressure probe is about 2cm too long:

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

jcohenadad, 2025-06-09:
It can be separated, so let's just find another, smaller, connector:

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

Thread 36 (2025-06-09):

Incompatible t-connector and pressure probe

jcohenadad, 2025-06-09:
I noticed the fitting is not perfect (pressure probe thread is smaller than t-connector), leading to water leak.

The pressure probe has the following dimension: NPT1/8
And the [t-connector](https://www.amazon.ca/dp/B0D3D3DNLM?ref=ppx_yo2ov_dt_b_fed_asin_title&th=1) is: 1/8" Fnpt x 1/8" Mnpt x 1/8" Mnpt

So it _looks_ like it should fit???

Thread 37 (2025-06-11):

temperature sensor (MAX31855) only occasionally reports -1000°C when powered by the AC/DC supply

jcohenadad, 2025-06-11:
temperature sensor (MAX31855) only occasionally reports `-1000°C` **when powered by the AC/DC supply** but works fine when powered by your **laptop USB** strongly suggests a **power integrity issue**, likely related to:

---

### ✅ Root Causes

1. **Noise or ripple** from the AC/DC converter — the MAX31855 is sensitive to unstable power.
2. **Ground loop or floating ground** — if the GND of the sensor and Arduino isn’t solid.
3. **Insufficient decoupling** — no capacitor near the MAX31855 VCC/GND to smooth power spikes.
4. **Poor connection or EMI** — long wires from thermocouple picking up noise when not shielded.

---

### ✅ Fixes / Diagnostics

#### 1. **Add a Decoupling Capacitor**

Place a **0.1 µF ceramic capacitor** between **VCC and GND** as close as possible to the MAX31855 breakout.

#### 2. **Test VCC Stability**

Use a multimeter or oscilloscope (if available) to check the **5 V rail** under load when using the AC/DC converter. Ripple >100 mV may cause glitches.

#### 3. **Try an Electrolytic Bulk Cap**

If ripple is significant, try adding a **10 µF–100 µF electrolytic capacitor** in parallel with the 0.1 µF near the MAX31855.

#### 4. **Check Grounds**

Ensure **only one ground reference** between the Arduino and MAX31855. Loose wires or poor terminal contacts can introduce ground shifts.

#### 5. **Shield Thermocouple Wires**

If you're using unshielded thermocouple wires:

* Try twisting them together.
* Move them away from power/inductive sources.
* If you can: use a **shielded thermocouple cable**, with shield connected to **GND** at one end only (Arduino side).

---

### ✅ Quick Test

Power the Arduino via the AC/DC adapter **but also connect the USB to your laptop**, even without uploading code. If this fixes the glitch, it confirms it's a **ground/noise problem**, since USB often stabilizes ground.

---

Let me know if you want to measure or filter the power supply further — or if you want to test a capacitor on a breadboard first.

jcohenadad, 2025-06-11:
> Power the Arduino via the AC/DC adapter but also connect the USB to your laptop, even without uploading code. If this fixes the glitch, it confirms it's a ground/noise problem, since USB often stabilizes ground.

I did this test but still see the glitches.

jcohenadad, 2025-06-11:
Great diagnostic step — and the fact that you **still get glitches even with USB connected** narrows it down. Here’s how to interpret it:

---

### 🔍 Updated Analysis

Since USB *does not* eliminate the issue:

* It's **not just a floating ground issue**.
* The issue is more likely caused by **power quality (ripple/noise)** or **electromagnetic interference (EMI)** from the AC/DC converter itself.
* Alternately, it could be **a grounding issue upstream**, such as unstable GND at the MAX31855 due to poor routing, bad contacts, or missing decoupling.

---

### ✅ Next Best Steps

#### 1. **Add Decoupling Capacitor (if not already done)**

Place a **0.1 µF ceramic capacitor** across **VCC and GND** *directly at the MAX31855 breakout* (if you're using a breakout board, solder it on the header).

Optionally also add a **10–100 µF electrolytic** for bulk decoupling.

#### 2. **Try USB Power + VIN Disconnect**

Temporarily **disconnect the AC/DC VIN to the Nano**, and power it **only via USB**. If the glitches stop, then it's almost certainly **AC/DC noise**.

#### 3. **Power Converter Isolation Test**

Try powering the Arduino from:

* **A regulated bench supply** (if available)
* **A USB battery bank** (clean power)

If the glitch disappears in both cases → your AC/DC converter is too noisy for digital sensors.

#### 4. **Check Wiring Quality**

Verify:

* The **GND** and **VCC** lines from the converter to the Nano and MAX31855 are **not long/thin**.
* The **thermocouple is tightly inserted** and wires aren’t loose.
* **No shared high-current paths** with inductive devices (like relays, solenoids, etc).

#### 5. **Try Averaging or Filtering in Code (optional workaround)**

If this is a transient spike, you could:

```cpp
float temp = thermocouple.readCelsius();
if (temp > -100 && temp < 150) {
  // Acceptable range
  lastValidTemp = temp;
}
else {
  // Skip update, keep old
  temp = lastValidTemp;
}
```

---

### Optional: Use an Alternate Power Regulator

If the AC/DC supply is generic or switching-type, consider trying:

* A **linear 5V regulator** (e.g., 7805 or LDO) fed by 12V
* Or a **better regulated 5V module** (e.g., Mean Well IRM-05-5 or similar)

jcohenadad, 2025-06-11:
Thin power wires can absolutely cause glitches — especially with digital sensors like the MAX31855 that are sensitive to voltage dips or noise. Here's what you need to know:

---

### 🔧 **Best Practices for Power/GND Lines (especially for sensors)**

#### ✅ **Wire Gauge**

* Use **22 AWG or thicker** (lower number = thicker wire) for power and ground.
* For high-reliability connections over >10 cm, even **20 AWG** is recommended.
* Avoid anything thinner than **26 AWG** for power — that’s borderline for short jumpers only.

#### ✅ **Length**

* Keep power and ground wires **as short as practical**.
* If longer than \~20 cm, use **twisted pair** or **route them together** to reduce noise pickup and voltage drop.

#### ✅ **Star Grounding**

* Connect **each sensor’s GND directly to the Nano’s GND rail**, not daisy-chained from another sensor.
* This avoids introducing return current noise from one device into another.

#### ✅ **Decoupling Capacitors**

* Add a **0.1 µF ceramic** and optionally a **10–100 µF electrolytic** *close to each sensor’s power pins*.
* These capacitors suppress both high-frequency noise and low-frequency ripple.

#### ✅ **Use GND Plane (on PCB)**

If you're routing this on a PCB:

* Use a **solid GND pour** (polygon) underneath all components.
* Route power traces **wide** (at least 0.5 mm; ideally 1 mm).

---

### 🧪 Quick Test: Replace Wires

Try this:

* Replace the thin wires to your Nano and MAX31855 with **short, thick jumper wires** (e.g., dupont-style with 22 AWG silicone wire).
* If the glitch goes away → **you’ve confirmed poor power delivery is the culprit**.

jcohenadad, 2025-06-20:
Actually, the breakout board _already_ includes the capacitors:

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

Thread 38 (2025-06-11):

Replace terminal screws with connectors

jcohenadad, 2025-06-11:
> I don't like screw terminal, they are cumbersome to work with-- i'd prefer connectors

If you'd like to switch from screw terminals to something <strong>cleaner, faster, and more compact</strong>, here are solid connector options tailored for your espresso machine PCB project:</p>
<hr>
<h3>🔌 <strong>1. JST XH (2.5mm pitch)</strong> — <em>Robust and easy</em></h3>
<ul>
<li>
<p>✅ Very common in hobby and industrial projects</p>
</li>
<li>
<p>✅ Latch mechanism prevents accidental disconnection</p>
</li>
<li>
<p>✅ Available in 2–12 pin versions</p>
</li>
<li>
<p>✅ Crimped wires or pre-crimped cables available</p>
</li>
<li>
<p>❌ Slightly bulkier than 1.25mm pitch connectors</p>
</li>
</ul>
<p><strong>Use when:</strong> You want reliability and easy replacement of sensor/display cables.</p>
<hr>
<h3>🔌 <strong>2. JST GH (1.25mm pitch)</strong> — <em>Small and sleek</em></h3>
<ul>
<li>
<p>✅ Compact, low-profile (often used in drones, displays)</p>
</li>
<li>
<p>✅ Secure locking tab</p>
</li>
<li>
<p>✅ Pre-crimped wires are available (e.g., for your IPS display)</p>
</li>
<li>
<p>❌ A bit delicate; crimping wires yourself is tricky</p>
</li>
</ul>
<p><strong>Use when:</strong> Space is tight and you're dealing with small sensors like FDC1004 or thermocouples.</p>
<hr>
<h3>🔌 <strong>3. Molex KK 254 (2.54mm pitch)</strong> — <em>Breadboard compatible</em></h3>
<ul>
<li>
<p>✅ Same pitch as typical 0.1” headers (e.g., Arduino)</p>
</li>
<li>
<p>✅ Compatible with standard Dupont jumper cables</p>
</li>
<li>
<p>✅ Easily available, crimping tools are affordable</p>
</li>
<li>
<p>❌ No latch by default (but optional housing with latch exists)</p>
</li>
</ul>
<p><strong>Use when:</strong> You want basic, swappable connectors without too much tooling effort.</p>
<hr>
<h3>🔌 <strong>4. Micro-Fit 3.0 or Mini-Fit Jr. (Molex)</strong> — <em>Power-focused</em></h3>
<ul>
<li>
<p>✅ Great for high current (e.g., powering your whole board from AC/DC converter)</p>
</li>
<li>
<p>✅ Very secure with locking tabs</p>
</li>
<li>
<p>✅ Used in ATX power supplies, automotive</p>
</li>
<li>
<p>❌ Bigger and pricier than JST/GH</p>
</li>
</ul>
<p><strong>Use when:</strong> You're running higher power (e.g., &gt;1A) and want reliability.</p>
<hr>
<h3>🛠️ <strong>Recommended Setup for Your Project</strong></h3>

Connection | Suggested Connector
-- | --
OLED / IPS display | JST GH 1.25mm (you already use this)
Thermocouple | JST XH 2.5mm or KK 254
FDC electrodes | JST XH 3-pin or GH 1.25mm
Pressure transducer | JST XH 3-pin
Power in (from AC/DC) | Molex Mini-Fit Jr. 2-pin

<hr>
<h3>🧰 Crimping Tools</h3>
<p>If you're crimping your own:</p>
<ul>
<li>
<p><strong>Engineer PA-09</strong>: very good manual crimper for small contacts</p>
</li>
<li>
<p><strong>IWISS tools</strong>: affordable sets for JST/Molex</p>
</li>
<li>
<p><strong>Pre-crimped leads</strong>: buy these if you want to avoid manual crimping</p>
</li>
</ul>
<hr>
<p>Would you like a KiCad connector library suggestion or a quick mockup with footprints for one of these types?</p></body></html>

Closed 2025-06-20.

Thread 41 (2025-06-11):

Use SHLD1 from FDC1004 to help with shielding from the metallic structure

jcohenadad, 2025-06-11:
I'm having difficulties

jcohenadad, 2025-06-11:
> why can't I simply connect the SHLD pin to the metallic structure of the espresso machine?

Great question — and it gets at the heart of **how capacitive shielding actually works**. Here's why **you should *not* connect the SHLD pin to the espresso machine's metallic frame**:

---

### ❌ Why You *Shouldn't* Connect `SHLD` to the Metal Frame

1. **The SHLD pin is an *active* shield, not ground.**

   * It outputs a **buffered version of the sensor signal**, dynamically following its voltage.
   * Its purpose is to **match the voltage of the sensing electrode**, so that no current flows between the shield and the sensor (→ minimal parasitic capacitance).

2. **The espresso machine frame is at ground potential.**

   * Connecting SHLD to ground (or anything large and conductive at a different potential) **defeats its purpose**.
   * Instead of shielding the sensor, you’ll actually increase parasitic capacitance and possibly introduce noise.

3. **You risk shorting the SHLD output.**

   * The SHLD pin is not designed to sink or source significant current — tying it to ground could overload or damage the internal buffer of the FDC1004.

---

### ✅ What You *Should* Do Instead

* Connect the SHLD pin to a **dedicated shielding conductor or plane**, e.g.:

  * A piece of copper tape
  * A PCB plane behind the sensing electrodes
  * Foil glued behind your electrodes on the tank wall (electrically insulated from the frame)

This plane should:

* Be **physically between** the sensing electrodes and the espresso machine’s metal panel
* Be **electrically isolated** from the metal machine
* Be **only connected to the SHLD pin** (not to ground or VCC)

---

### 🔁 Analogy

Think of the SHLD as a **transparent bubble** around your sensor:

* If you tie that bubble to the metal frame (ground), it becomes a **metal cage** that distorts your measurement.
* If you let the bubble “float” at the same potential as your sensing pin (via SHLD), it **blocks interference** without affecting your signal.

---

### 🧪 Optional Test

You can experimentally see the difference:

* Try measuring with SHLD floating
* Then with SHLD connected to a foil plane
* Then (carefully) to ground — and see how noisy or flat your readings get

---

Let me know your current wiring setup and space constraints — I can sketch a layout using SHLD effectively in your case.

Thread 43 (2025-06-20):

Not enough capacitive range when metallic panel close to electrodes

jcohenadad, 2025-06-20:
Because the metallic panel of the espresso machine is very close to the electrodes (about 1cm), the capacitance is drastically increased, and the range falls outside the specs of the FDC1004.

I should make use of the shield pin of the FDC1004 and add a shield between the metallic plate and the electrodes, as suggested in https://github.com/jcohenadad/espresso-pimpup/issues/23#issuecomment-2773599326

jcohenadad, 2025-06-20:
Duplicate of #41

Closed 2025-06-20.

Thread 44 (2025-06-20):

Wrong 3D library design for arduino

jcohenadad, 2025-06-20:
should be female:

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

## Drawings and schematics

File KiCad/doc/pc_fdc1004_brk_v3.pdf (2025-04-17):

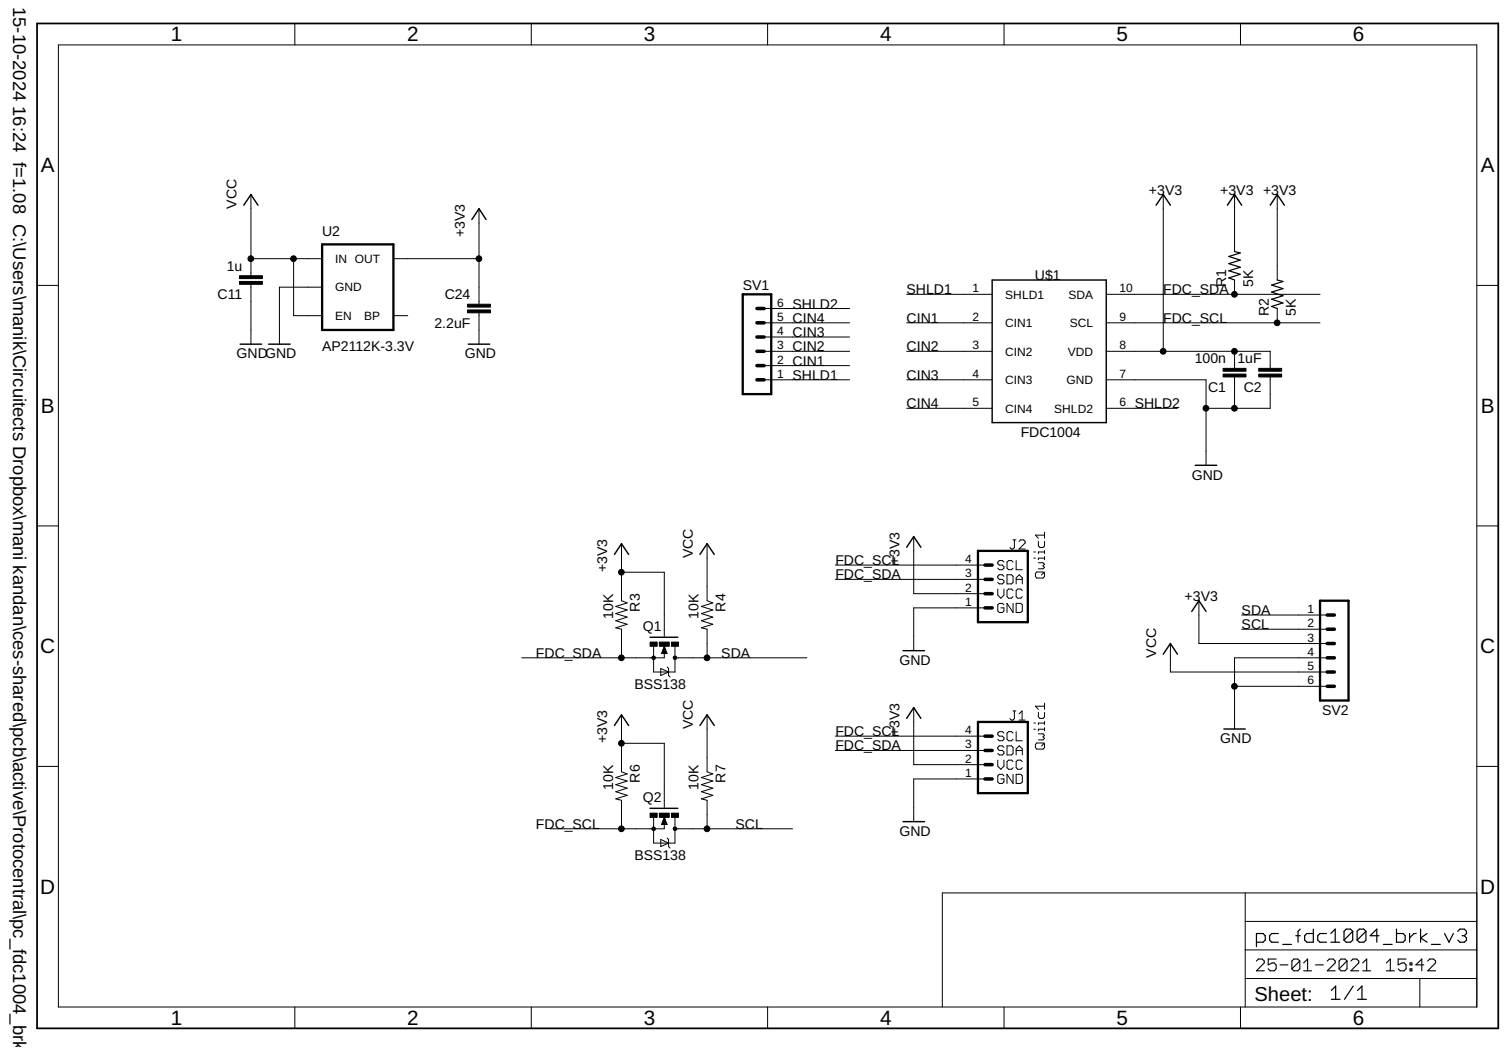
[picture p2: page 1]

15-10-2024 16:24 f=1.08 C:\Users\manik\Circuitects Dropbox\mani kandan\ces-shared\pcb\active\Protocentral\pc_fdc1004_brk_v3\pc_fdc1004_brk_v3.sch (Sheet: 1/1)

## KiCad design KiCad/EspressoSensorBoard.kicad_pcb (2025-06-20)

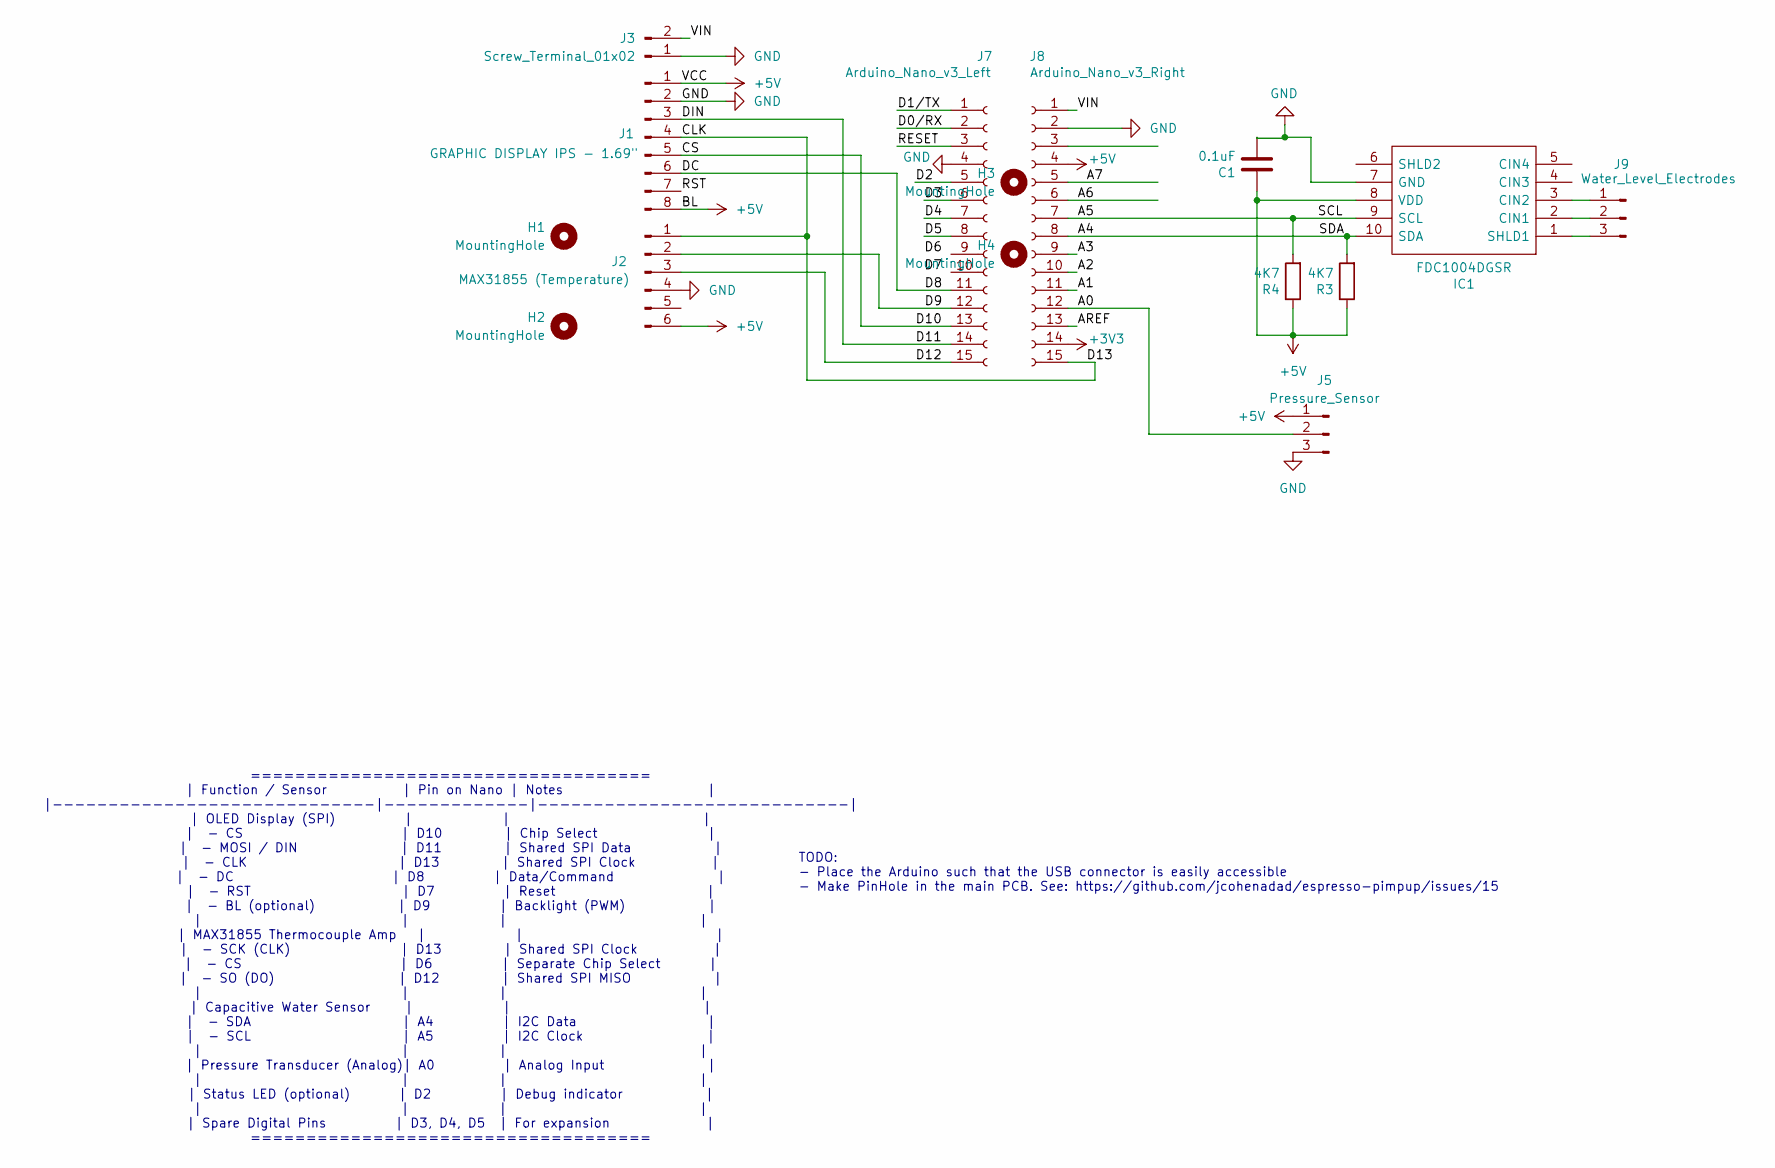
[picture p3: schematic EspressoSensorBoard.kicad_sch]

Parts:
C1: 0.1uF; C_0805_2012Metric_Pad1.18x1.45mm_HandSolder
H1, H2, H3, H4: MountingHole; MountingHole_2.2mm_M2
IC1: FDC1004DGSR; MSOP-10_3x3mm_P0.5mm; Mouser Part Number 595-FDC1004DGSR
J1: GRAPHIC DISPLAY IPS - 1.69"; JST_GH_BM08B-GHS-TBT_1x08-1MP_P1.25mm_Vertical
J2: MAX31855 (Temperature); PinHeader_1x06_P2.54mm_Vertical
J3: Screw_Terminal_01x02; PinHeader_1x02_P2.54mm_Vertical
J5: Pressure_Sensor; PinHeader_1x03_P2.54mm_Vertical
J7: Arduino_Nano_v3_Left; PinSocket_1x15_P2.54mm_Vertical
J8: Arduino_Nano_v3_Right; PinSocket_1x15_P2.54mm_Vertical
J9: Water_Level_Electrodes; PinHeader_1x03_P2.54mm_Vertical
R3, R4: 4K7; R_0805_2012Metric_Pad1.20x1.40mm_HandSolder

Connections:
+3V3: J8.14
+5V: C1.1, IC1.8 (VDD), J1.1, J1.8, J2.6, J5.1, J8.4, R3.1, R4.1
/A0: J5.2, J8.12
/A1: J8.11
/A2: J8.10
/A3: J8.9
/A4: IC1.10 (SDA), J8.8, R3.2
/A5: IC1.9 (SCL), J8.7, R4.2
/A6: J8.6
/A7: J8.5
/AREF: J8.13
/CLK: J1.4, J2.1, J8.15
/CS: J1.5, J7.13
/D0/RX: J7.2
/D1/TX: J7.1
/D2: J7.5
/D3: J7.6
/D4: J7.7
/D5: J7.8
/D8: J1.6, J7.11
/D9: J2.2, J7.12
/D11: J1.3, J7.14
/D12: J2.3, J7.15
/RESET: J7.3
/RST: J1.7
/VIN: J3.2, J8.1
GND: C1.2, IC1.7 (GND), J1.2, J2.4, J3.1, J5.3, J7.4, J8.2
unnamed: IC1.2 (CIN1), J9.2
unnamed: IC1.3 (CIN2), J9.1
unnamed: IC1.1 (SHLD1), J9.3

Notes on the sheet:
==================================== | Function / Sensor | Pin on Nano | Notes | |-----------------------------|-------------|----------------------------| | OLED Display (SPI) | | | | - CS | D10 | Chip Select | | - MOSI / DIN | D11 | Shared SPI Data | | - CLK | D13 | Shared SPI Clock | | - DC | D8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
TODO: - Place the Arduino such that the USB connector is easily accessible - Make PinHole in the main PCB. See: https://github.com/jcohenadad/espresso-pimpup/issues/15

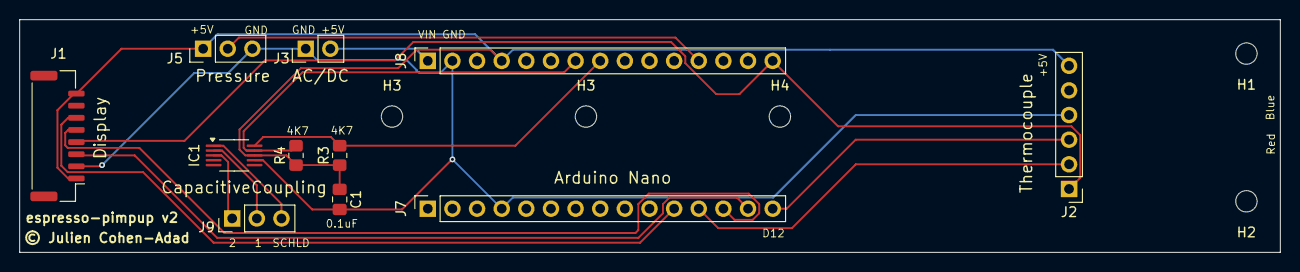
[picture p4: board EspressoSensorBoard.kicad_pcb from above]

Board: 2 copper layers, 130.0 x 24.0 mm, 16 parts (0 on the bottom side), 15 nets.

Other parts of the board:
H3#2: MountingHoles_Rancilio; MountingHole_2.2mm_M2

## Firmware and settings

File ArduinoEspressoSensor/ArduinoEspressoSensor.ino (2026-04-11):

#include <RTClib.h>
#include <Arduino.h>
#include <Adafruit_GFX.h>
#include <Adafruit_SSD1306.h>
#include <Adafruit_MAX31855.h>
#include <Adafruit_ST7789.h>
#include <SPI.h>
#include <Wire.h>
#include <Protocentral_FDC1004.h>

// ─── Debugging ───────────────────────────────────────────────────────────────
#define DEBUG_TEMPERATURE false
#define DEBUG_PRESSURE    false
#define DEBUG_CAPACITANCE true

// ─── Loop duration ───────────────────────────────────────────────────────────
#define LOOP_DURATION 500  // ms

// ─── Display ─────────────────────────────────────────────────────────────────
#define TFT_CS   10
#define TFT_RST  -1
#define TFT_DC    8
Adafruit_ST7789 tft = Adafruit_ST7789(TFT_CS, TFT_DC, TFT_RST);

// ─── Temperature sensor ──────────────────────────────────────────────────────
#define MAX_CS 9
Adafruit_MAX31855 thermocouple(MAX_CS);

// ─── Pressure sensor ─────────────────────────────────────────────────────────
int   sensorPin = A0;
float pressure  = 0.0;

// ─── Capacitive coupling (water level) ───────────────────────────────────────
// FDC1004 → I²C: SCL → A5 (Uno) / SCL (Nano), SDA → A4 (Uno) / SDA (Nano)
#define CHANNEL     0
#define MEASUREMENT 0
#define LOWER_BOUND 6.0    // min capacitance in pF (calibrate experimentally)
#define UPPER_BOUND 6.9    // max capacitance in pF

int     capdac           = 0;
int16_t msb;
int32_t capacitance;
float   capacitance_pF;
float   capacitance_pF_old = LOWER_BOUND;
FDC1004 fdc;

// ─── Brewing state ───────────────────────────────────────────────────────────
bool          isBrewing         = false;
unsigned long brewStartTime     = 0;
float         brewDuration      = 0.0;
const float   pressureThreshold = 0.5;  // Bar
int           blinkCount        = 0;
unsigned long lastBlinkTime     = 0;
bool          showTimer         = true;

// ─── RTC ─────────────────────────────────────────────────────────────────────
RTC_DS3231 rtc;

// ─── FIX: last-drawn value cache (prevents unnecessary redraws / flicker) ────
int lastTemp             = -9999;
int lastPressureDisplay  = -9999;   // stored as tenths of Bar (×10)
int lastWater            = -9999;

// ─────────────────────────────────────────────────────────────────────────────
void setup() {
  Serial.begin(9600);
  delay(1000);

  tft.init(240, 280);
  tft.setRotation(3);
  tft.fillScreen(ST77XX_BLACK);
  tft.setTextWrap(false);

  thermocouple.begin();
  pinMode(sensorPin, INPUT);
  Wire.begin();

  drawStaticLayout();
}

// ─────────────────────────────────────────────────────────────────────────────
void loop() {
  // ── Water level (capacitance) ─────────────────────────────────────────────
  fdc.configureMeasurementSingle(MEASUREMENT, CHANNEL, capdac);
  fdc.triggerSingleMeasurement(MEASUREMENT, FDC1004_100HZ);
  delay(LOOP_DURATION);  // ≥9 ms required for conversion; doubles as loop cadence

  uint16_t value[2];
  if (!fdc.readMeasurement(MEASUREMENT, value)) {
    msb           = (int16_t)value[0];
    capacitance   = 457L * msb + 3028L * capdac * 1000L;
    capacitance_pF = capacitance / 1e6;

    if (DEBUG_CAPACITANCE) {
      Serial.print("capacitance_pF: ");
      Serial.print(capacitance_pF, 4);
      Serial.println(" pF");
    }
  }

  // Clamp to last valid reading when out of range
  if (capacitance_pF < LOWER_BOUND || capacitance_pF > UPPER_BOUND) {
    capacitance_pF = capacitance_pF_old;
    if (DEBUG_CAPACITANCE) Serial.println("Capacitance out of bounds — using previous value.");
  } else {
    capacitance_pF_old = capacitance_pF;
  }

  float water_level = 100.0 - (capacitance_pF - LOWER_BOUND) / (UPPER_BOUND - LOWER_BOUND) * 100.0;

  if (DEBUG_CAPACITANCE) {
    Serial.print("Water Level: ");
    Serial.print((int)water_level);
    Serial.println(" %");
  }

  // ── Temperature ───────────────────────────────────────────────────────────
  float temperature = thermocouple.readCelsius();
  if (isnan(temperature)) temperature = -1000;

  if (DEBUG_TEMPERATURE) {
    Serial.print("Temperature [°C]: ");
    Serial.println(temperature);
  }

  // ── Pressure ─────────────────────────────────────────────────────────────
  int   pressure_voltage = analogRead(sensorPin);
  float vin              = (pressure_voltage * 5.0) / 1024.0;
  pressure               = (vin < 0.5) ? 0.0 : (vin * 20.0) - 10.0;

  if (DEBUG_PRESSURE) {
    Serial.print("Pressure ADC: "); Serial.println(pressure_voltage);
    Serial.print("Pressure [Bar]: "); Serial.println(pressure);
  }

  Serial.println("------------------------");

  // ── Update display ────────────────────────────────────────────────────────
  updateDisplay(temperature, pressure, water_level);
}

// ─────────────────────────────────────────────────────────────────────────────
void print2digits(int number) {
  if (number < 10) tft.print("0");
  tft.print(number);
}

// ─────────────────────────────────────────────────────────────────────────────
void drawStaticLayout() {
  tft.fillScreen(ST77XX_BLACK);

  // Water-tank outline (drawn once; never overwritten by updateDisplay)
  int barX = 185, barY = 55, barW = 40, barH = 160;
  tft.drawRect(barX, barY, barW, barH, ST77XX_WHITE);
}

// ─────────────────────────────────────────────────────────────────────────────
void updateDisplay(float temperature, float pressure, float water_level) {

  // ── Quantise to display units ─────────────────────────────────────────────
  int tempDisplay     = (int)temperature;
  int pressureDisplay = (int)(pressure * 10);          // tenths of Bar
  int waterDisplay    = constrain((int)water_level, 0, 100);

  // ── Temperature (only redraw when integer °C changes) ────────────────────
  if (tempDisplay != lastTemp) {
    // Clear only the temperature region
    tft.fillRect(10, 25, 150, 70, ST77XX_BLACK);

    tft.setTextColor(ST77XX_RED, ST77XX_BLACK);  // bg colour prevents ghost pixels
    tft.setTextSize(6);
    tft.setCursor(20, 35);
    tft.print(tempDisplay);
    tft.setTextSize(4);
    tft.print(" C");

    lastTemp = tempDisplay;
  }

  // ── Pressure (only redraw when tenths-of-Bar value changes) ──────────────
  if (pressureDisplay != lastPressureDisplay) {
    tft.fillRect(10, 120, 150, 70, ST77XX_BLACK);

    tft.setTextColor(ST77XX_WHITE, ST77XX_BLACK);
    tft.setTextSize(6);
    tft.setCursor(20, 140);
    tft.print(pressure, 1);
    tft.setTextSize(4);
    tft.print(" B");

    lastPressureDisplay = pressureDisplay;
  }

  // ── Water level % + bar (only redraw when integer % changes) ─────────────
  if (waterDisplay != lastWater) {
    // Percentage label
    tft.fillRect(165, 10, 75, 30, ST77XX_BLACK);
    tft.setTextColor(ST77XX_CYAN, ST77XX_BLACK);
    tft.setTextSize(3);
    tft.setCursor(168, 15);
    tft.print(waterDisplay);
    tft.print("%");

    // Vertical bar graph
    const int barX = 185, barY = 55, barW = 40, barH = 160;

    // Clear interior (leave 1-px border)
    tft.fillRect(barX + 1, barY + 1, barW - 2, barH - 2, ST77XX_BLACK);

    // Fill from the bottom
    int fillH = (int)((waterDisplay / 100.0) * (barH - 2));
    if (fillH > 0) {
      tft.fillRect(barX + 1,
                   barY + barH - 1 - fillH,
                   barW - 2,
                   fillH,
                   ST77XX_BLUE);
    }

    // Redraw border (interior fill erases the inner edge of the rect)
    tft.drawRect(barX, barY, barW, barH, ST77XX_WHITE);

    lastWater = waterDisplay;
  }
}

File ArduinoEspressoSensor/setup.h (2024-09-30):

// =========================================
// ==== WATER RESERVOIR LEVEL DETECTION ====
// =========================================

// Water Reservoir probe Threshold value
const int WATER_RESERVOIR_THRESHOLD = 300; // Set this value slightly higher than the probe's value when NOT touching water 

// Ultrasonic Level Detection settings
const int LOW_WATER_THRESHOLD = 20; // If enabled, minimum water percentage before triggering "Refill water reservoir"
const long distanceFull = 50;    // Distance (mm) between the Ultrasonic sensor and water level with a full reservoir
const long distanceEmpty = 200;  // Distance (mm) between the Ultrasonic sensor and the bottom of the empty reservoir

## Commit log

2024-09-30 Added prototype arduino code
2024-10-13 Added code to measure pressure
2024-10-17 Working code with temperature, pressure and distance :)
2024-10-17 Clip pressure if Voltage is below 0.5V
    Due to noise fluctuation
2024-12-06 Updated list of material
2024-12-19 Working prototype with new TFT 1"69' display
2024-12-19 Removed conflict between TFT display and ultrasound PIN
2024-12-19 Working display for all sensors
2025-04-12 Replaced temperature sensor DB18 for thermocouple MAX31855
2025-04-15 Added cap sensor
2025-04-16 Added CST python script
    [result_sweep.csv]
2025-04-17 Added new CST results
    [result_sweep.csv]
2025-04-17 Added KiCad project
    [pc_fdc1004_brk_v3.brd]
2025-04-28 Added KiCad files
    [EspressoSensorBoard.kicad_pcb, EspressoSensorBoard.kicad_sch]
2025-05-30 Replaced ultrasound by capacitive coupling
    WIP
2025-05-30 Added documentation for Arduino CLI
2025-05-30 Renamed Arduino folder to match INO file
    Required by Arduino for compilation
2025-05-30 Working capacitance coupling
2025-05-30 Fixed capacitance code (I think...)
    [ArduinoEspressoSensor.ino]
2025-06-03 Fixed PIN for pressure
    [ArduinoEspressoSensor.ino]
2025-06-03 Implemented timer for brewing
2025-06-03 Added info about calibration
2025-06-11 Added min/max capacitance values for water tank
2025-06-11 removed timer for now (not working)
    [ArduinoEspressoSensor.ino]
2025-06-20 Use SCHLD1 pin from the FDC1004 capacitive sensor
    https://github.com/jcohenadad/espresso-pimpup/issues/43
    [EspressoSensorBoard.kicad_sch]
2025-06-20 Replaced screw terminal by Dupont male pins
    https://github.com/jcohenadad/espresso-pimpup/issues/38
    [EspressoSensorBoard.kicad_pcb, EspressoSensorBoard.kicad_sch]
2025-06-20 Updated PCB and Arduino code
    - Swapped D7 with D9 for easier routing
    - Removed connection to RST on the Display (should work without it)
    - Replaced connectors, notably using JST GH1.25mm for the display. https://github.com/jcohenadad/espresso-pimpup/issues/28
    - Changed 3D model for Arduino. https://github.com/jcohenadad/espresso-pimpup/issues/44
    - Connected pin to shielding on FDC1004. https://github.com/jcohenadad/espresso-pimpup/issues/41
    [EspressoSensorBoard.kicad_pcb, EspressoSensorBoard.kicad_sch]
2025-06-20 Minor modifs on the Kicad PCD
    [EspressoSensorBoard.kicad_pcb, EspressoSensorBoard.kicad_sch]
2025-06-20 Fixed missing connection
    [EspressoSensorBoard.kicad_pcb]
2025-06-20 Fixed arduino connector
    [EspressoSensorBoard.kicad_pcb, EspressoSensorBoard.kicad_sch]
2025-09-21 Add JST connector to README components list
2025-09-22 Add threading screws to display components list
    Added 4x 2mm metric threading screws to the display section.
2025-09-22 Update README with link for threading screws
2026-04-05 Updated schematic
2026-04-11 Calibrated water level-- added out-of-bound fix
    [ArduinoEspressoSensor.ino]
2026-04-11 Fixed inverted water level percentage
    [ArduinoEspressoSensor.ino]

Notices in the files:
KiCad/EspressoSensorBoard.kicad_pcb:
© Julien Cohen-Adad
